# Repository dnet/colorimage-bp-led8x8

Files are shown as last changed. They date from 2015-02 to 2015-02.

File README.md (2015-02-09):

Color Image Budapest 8 by 8 LED display driver
==============================================

Building and burning the firmware
---------------------------------

Dependencies: `make` `gcc-avr` `avrdude`

	make program

If you haven't changed the clock settings to 8 MHz and no clock divider,
you'll also need to run `make burn-fuse`

Protocol
--------

One-way communication is done in 1 byte serial (USART) packets @ 9600 bps:

	(MSB) RRRS PPPP (LSB)

 - 3 bits for row selection (0-7, 0 is the topmost)
 - 1 bit for side selection (0 is left, 1 is right)
 - 4 bits pixel payload (LSB is the rightmost)

### Examples ###

(dots represent unchanged pixels)

Packet: `01001011` (0x4b)

Display:

	. . . . . . . .
	. . . . . . . .
	. . . . . . . .
	. . . . . . . .
	x   x x . . . .
	. . . . . . . .
	. . . . . . . .
	. . . . . . . .

Packet: `11111111` (0xff)

Display:

	. . . . . . . .
	. . . . . . . .
	. . . . . . . .
	. . . . . . . .
	. . . . . . . .
	. . . . . . . .
	. . . . . . . .
	. . . . x x x x

Controller board
----------------

 - ATtiny2313 microcontroller running at 8 MHz (internal clock)
   - PORT B (PB0-PB1) for column addressing with a shift register
   - PORT D (PD2-PD5) for row addressing
 - 74HC138 3 to 8-line demux (row selection)
 - 74HC164 8 bit serial-in parallel-out shift register (column buffer)
 - transistors for driving

### Schematics ###

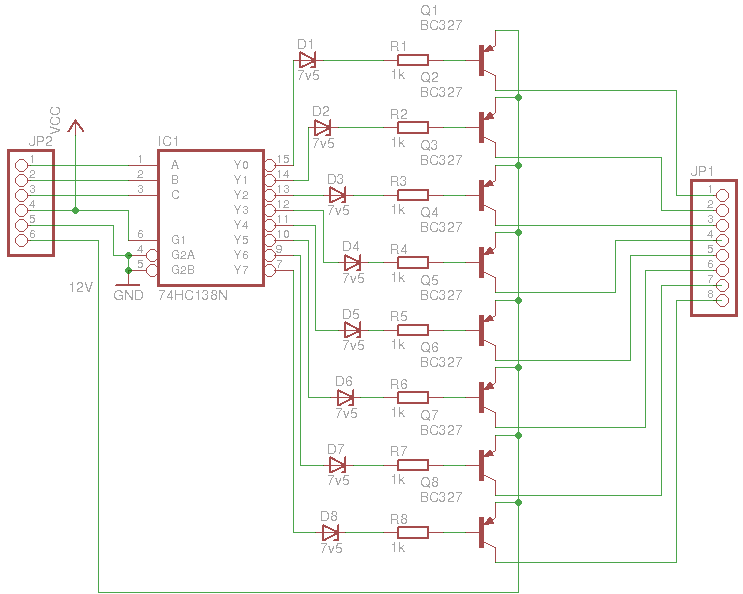
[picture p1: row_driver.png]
Row driver schematic


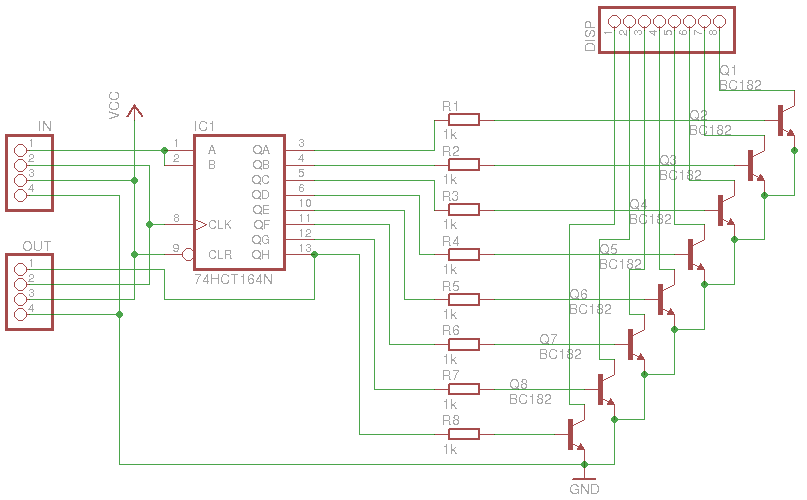
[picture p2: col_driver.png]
Col driver schematic


Display board layout
--------------------

 - 5 LEDs are in series for each pixel
 - rows are numbered from top to bottom
 - cols are numbered from right to left
 - `right` and `left` are referred to as when looking at the LEDs
 - row pins must be positive, col pins must be grounded for LEDs to light

ASCII art layout:

	.------------------------------.
	|        COLOR  IMAGE    (TOP) |
	|          BUDAPEST            |
	|                              |
	|          ++++++++ (row pins) |
	|                              |
	|                              |
	|                              |
	|                              |
	|          ........ (blank)    |
	|                              |
	|                              |
	|          ++++++++ (col pins) |
	|                              |
	| (RIGHT)   (back)      (LEFT) |
	'------------------------------'

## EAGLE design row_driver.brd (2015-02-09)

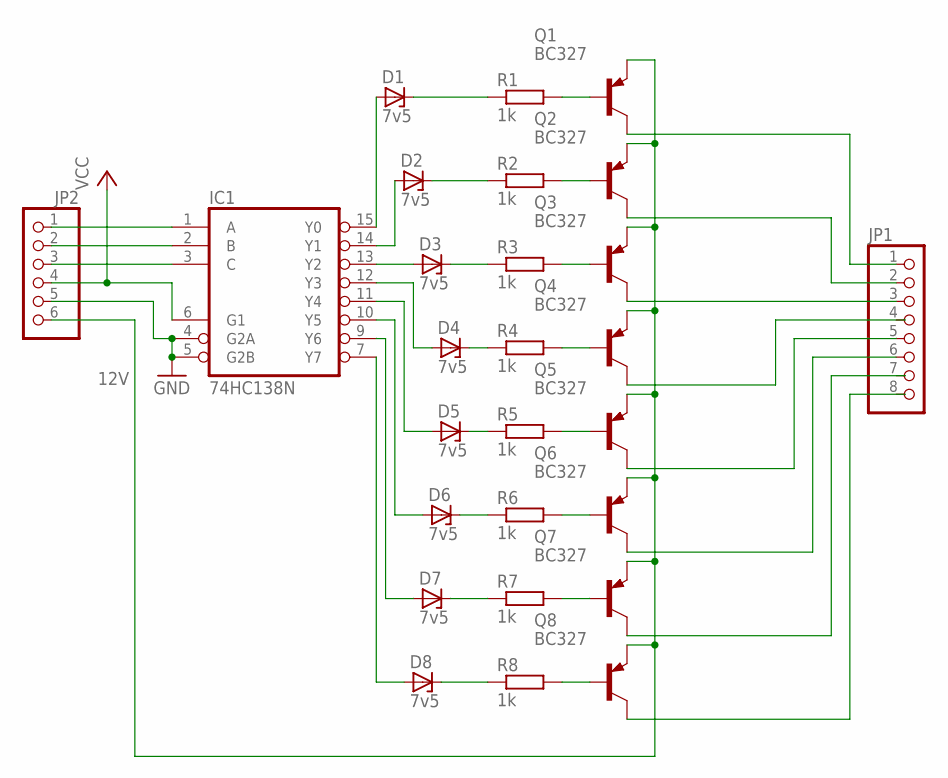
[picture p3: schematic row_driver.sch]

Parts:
D1, D2, D3, D4, D5, D6, D7, D8: 7v5; DO34Z7
IC1: 74HC138N; DIL16
JP1: PINHD-1X8; 1X08
JP2: PINHD-1X6; 1X06
Q1, Q2, Q3, Q4, Q5, Q6, Q7, Q8: BC327; TO92
R1, R2, R3, R4, R5, R6, R7, R8: 1k; 0207/12

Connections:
12V: JP2.6, Q1.1 (E), Q2.1 (E), Q3.1 (E), Q4.1 (E), Q5.1 (E), Q6.1 (E), Q7.1 (E), Q8.1 (E)
GND: IC1.4 (G2A), IC1.5 (G2B), IC1.8 (GND), JP2.5
unnamed: D1.A, IC1.15 (Y0)
unnamed: D5.A, IC1.11 (Y4)
unnamed: IC1.1 (A), JP2.1
unnamed: IC1.2 (B), JP2.2
unnamed: IC1.3 (C), JP2.3
unnamed: D4.C, R4.1
unnamed: Q4.2 (B), R4.2
unnamed: Q5.2 (B), R5.2
unnamed: D6.C, R6.1
unnamed: Q6.2 (B), R6.2
unnamed: Q7.2 (B), R7.2
unnamed: D7.C, R7.1
unnamed: D8.C, R8.1
unnamed: D1.C, R1.1
unnamed: D2.C, R2.1
unnamed: D3.C, R3.1
unnamed: Q3.2 (B), R3.2
unnamed: Q2.2 (B), R2.2
unnamed: Q1.2 (B), R1.2
unnamed: JP1.1, Q1.3 (C)
unnamed: JP1.2, Q2.3 (C)
unnamed: JP1.3, Q3.3 (C)
unnamed: JP1.5, Q5.3 (C)
unnamed: JP1.6, Q6.3 (C)
unnamed: D2.A, IC1.14 (Y1)
unnamed: D3.A, IC1.13 (Y2)
unnamed: D4.A, IC1.12 (Y3)
unnamed: D8.A, IC1.7 (Y7)
unnamed: D7.A, IC1.9 (Y6)
unnamed: D6.A, IC1.10 (Y5)
VCC: IC1.6 (G1), IC1.16 (VCC), JP2.4

Board: 2 copper layers, 27 parts (0 on the bottom side), 33 nets, no tracks yet.

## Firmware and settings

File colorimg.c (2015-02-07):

#include <avr/io.h>
#include <avr/interrupt.h>
#include <util/delay.h>

#define NUM_ROWS 8
#define ROW_PORT PORTD
#define ROW_DDR DDRD
#define ROW_OFFSET 2
#define COL_PORT PORTB
#define COL_DDR DDRB
#define COL_DATA 1
#define COL_CLOCK 2
#define ROW_MASK ((NUM_ROWS - 1) << ROW_OFFSET)

volatile uint8_t framebuf[NUM_ROWS];

#define TIMER1_PRESCALE_1 1
#define TIMER1_PRESCALE_8 2
#define TIMER1_PRESCALE_64 3
#define TIMER1_PRESCALE_256 4
#define TIMER1_PRESCALE_1024 5

volatile uint8_t cur_row = 0;

ISR( TIMER1_COMPA_vect ) {
	if (++cur_row >= NUM_ROWS) cur_row = 0;
}

#define  LEFT_SIDE 0x00
#define RIGHT_SIDE 0x10

ISR( USART_RX_vect  ) {
	uint8_t incoming, row, side, mask, pixels;
	
	incoming = UDR;
	row = incoming >> 5;
	side = incoming & 0x10;
	mask = (side == RIGHT_SIDE) ? 0xF0 : 0x0F;
	pixels = incoming & 0x0F;
	
	if (side == LEFT_SIDE) pixels <<= 4;
	
	framebuf[row] = (framebuf[row] & mask) | pixels;
}

int main(void) {

	COL_DDR |= COL_DATA | COL_CLOCK;
	ROW_DDR |= ROW_MASK;

	for (uint8_t row = 0; row < NUM_ROWS; row++) {
		framebuf[row] = row | ((row + 1) << 4);
	}

	const uint16_t brr = F_CPU / 16 / 9600 - 1;
	UBRRL = brr & 0xFF;
	UBRRH = brr >> 8;
	UCSRB |= _BV(RXEN) | _BV(RXCIE);

	TCCR1B = (1 << WGM12) | TIMER1_PRESCALE_1;
	OCR1A = (uint16_t)20000;

	TIMSK |= 1 << OCIE1A;   // Output Compare Interrupt Enable (timer 1, OCR1A)
	sei();                 // Set Enable Interrupts

	uint8_t disp_row = NUM_ROWS - 1;

	while (1) {
		while (disp_row == cur_row);
		disp_row = cur_row;

		uint8_t bit, fbrow;
		fbrow = framebuf[cur_row];
		for (bit = 0x80; bit; bit >>= 1) {
			COL_PORT = (fbrow & bit) == bit ? COL_DATA : 0;
			COL_PORT |= COL_CLOCK;
			COL_PORT &= ~COL_CLOCK;
		}
		ROW_PORT = (ROW_PORT & ~ROW_MASK) | (cur_row << ROW_OFFSET);
	}
}

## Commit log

2015-01-22 added row driver schematic
    [row_driver.brd, row_driver.sch]
2015-01-22 row_driver: fixed R8-Q8 wire
    [row_driver.sch]
2015-01-30 fixed ROW_MASK (external demux)
    [colorimg.c]
2015-01-30 replaced direct drive with bit-bang SPI
    [colorimg.c]
2015-02-07 updated README to reflect prototype hardware
2015-02-09 added column driver schematics
    [col_driver.sch]
2015-02-09 row_driver: yet another wire gap
    [row_driver.sch]
2015-02-09 row_driver: added GND and VCC
    [row_driver.brd, row_driver.sch]
